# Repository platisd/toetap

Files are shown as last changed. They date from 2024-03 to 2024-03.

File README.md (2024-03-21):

# ToeTap
A human interface device for your toes 🦶⌨️

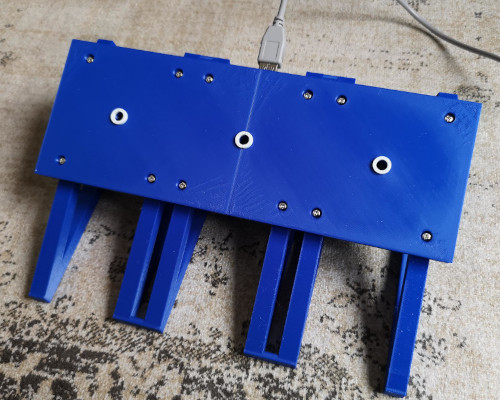
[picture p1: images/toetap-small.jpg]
toetap top view


## What is ToeTap?

ToeTap is a minimalist USB keyboard and mouse that you control by tapping your toes.
It's designed to be used as a foot pedal for gamers, video makers and editors or anyone who wants to keep their hands free while working in front of a computer.
I use it to scroll through my script while recording videos because I hate moving my hand away just to scroll. It shows a bit on the video and it's annoying.
You can easily adjust it to perform any keyboard or mouse action you want. With up to 3 inputs and no moving parts, it's a simple and reliable tool that you can use to improve your workflow.

Compared to commercial foot pedals, ToeTap is probably slightly cheaper if you know how to solder and can program an Arduino. It's also infinitely more customizable since, you know, it's open source. 🍹

## How does it work?

ToeTap is made of some hardware that involve various components, custom made PCBs and a 3D printed case. It's controlled by an Arduino Pro Micro clone, which is a small board that can act as a USB keyboard or mouse. The ATmega32U4 microcontroller by Microchip is connected to 3 photoresistors that are used to detect when you tap/step on them.

### Hardware

The following components are necessary to build ToeTap:
- 3x [ToeTap PCBs](https://www.pcbway.com/project/shareproject/ToeTap_USB_Controller_7fb3b714.html)
- Arduino Pro Micro clone in a "square" form factor where the USB port is part of the board
  - It is often marketed as `Mini SS Micro ATMEGA32U4`
  - You may need to add some electrical tape on the USB side to make sure it doesn't wiggle when you connect it
- 9x 220Ω resistors
- [3D-printed components](https://www.tinkercad.com/things/i6qfPpNWuRz-toetap)

#### PCB Assembly

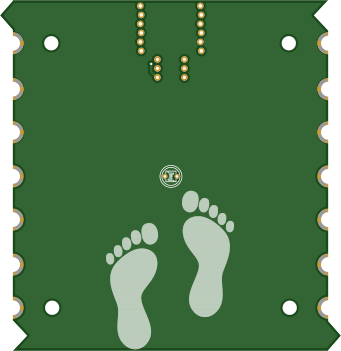
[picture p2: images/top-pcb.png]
top pcb layout
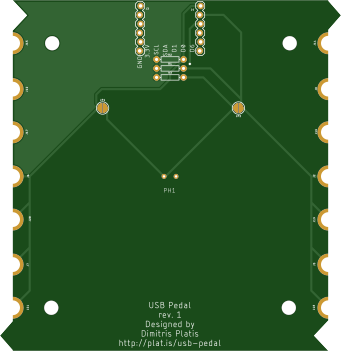
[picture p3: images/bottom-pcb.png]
bottom pcb layout


To build a fully-fledged ToeTap you will need to solder 3 of the ToeTap PCBs together. The PCBs are designed to be soldered together side by side, with the photoresistors on the top side and everything else on the bottom side. The photoresistors are used to detect when you tap on the ToeTap. The bottom side of the PCBs is where the microcontroller and the resistors are soldered.
Additionally, on the bottom side of the two "side" PCBs, you need to solder the "pad" facing towards the middle PCB. By soldering the PCBs together AND the corresponding pads, you will be able to get all the PCBs to work together as a single unit. The pads of the middle PCB should be left unsoldered.
If you need more detailed instructions, open an issue and I'll be happy to help you out.

### Software

The software is written in C++ and is designed to be compiled with the Arduino IDE.
Some basic filtering is applied to the photoresistor readings to detect when you tap on the ToeTap. The readings are then used to trigger a keyboard or mouse action. The software is designed to be easily customizable, so you can change the keybindings and the sensitivity of the ToeTap to suit your needs.

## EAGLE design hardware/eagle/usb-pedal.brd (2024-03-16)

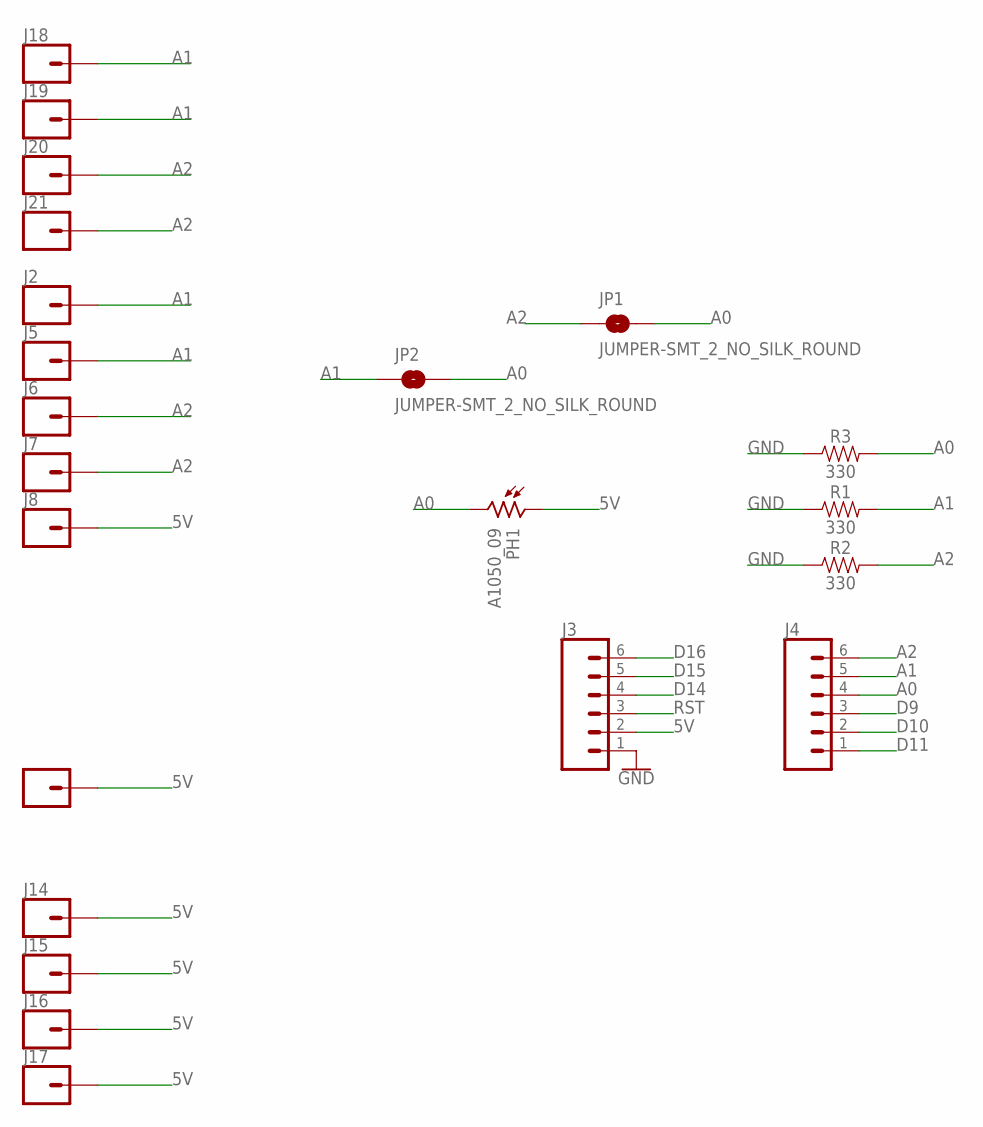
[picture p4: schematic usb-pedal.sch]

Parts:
J2, J5, J6, J7, J8, J12, J14, J15, J16, J17, J18, J19, J20, J21: CONN_01SMTSO-256-ET-0.165DIA; SMTSO-256-ET-0.165DIA
J3, J4: CONN_06LOCK; 1X06_LOCK
JP1, JP2: JUMPER-SMT_2_NO_SILK_ROUND; SMT-JUMPER_2_NO_SILK_ROUND
PH1: A1050_09; T0-46-A10XX
R1, R2, R3: 330; AXIAL-0.3

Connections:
5V: J3.2, J8.P$1, J12.P$1, J14.P$1, J15.P$1, J16.P$1, J17.P$1, PH1.1
A0: J4.4, JP1.2, JP2.2, PH1.2, R3.P$2 (2)
A1: J2.P$1, J4.5, J5.P$1, J18.P$1, J19.P$1, JP2.1, R1.P$2 (2)
A2: J4.6, J6.P$1, J7.P$1, J20.P$1, J21.P$1, JP1.1, R2.P$2 (2)
D9: J4.3
D10: J4.2
D11: J4.1
D14: J3.4
D15: J3.5
D16: J3.6
GND: J3.1, R1.P$1 (1), R2.P$1 (1), R3.P$1 (1)
RST: J3.3

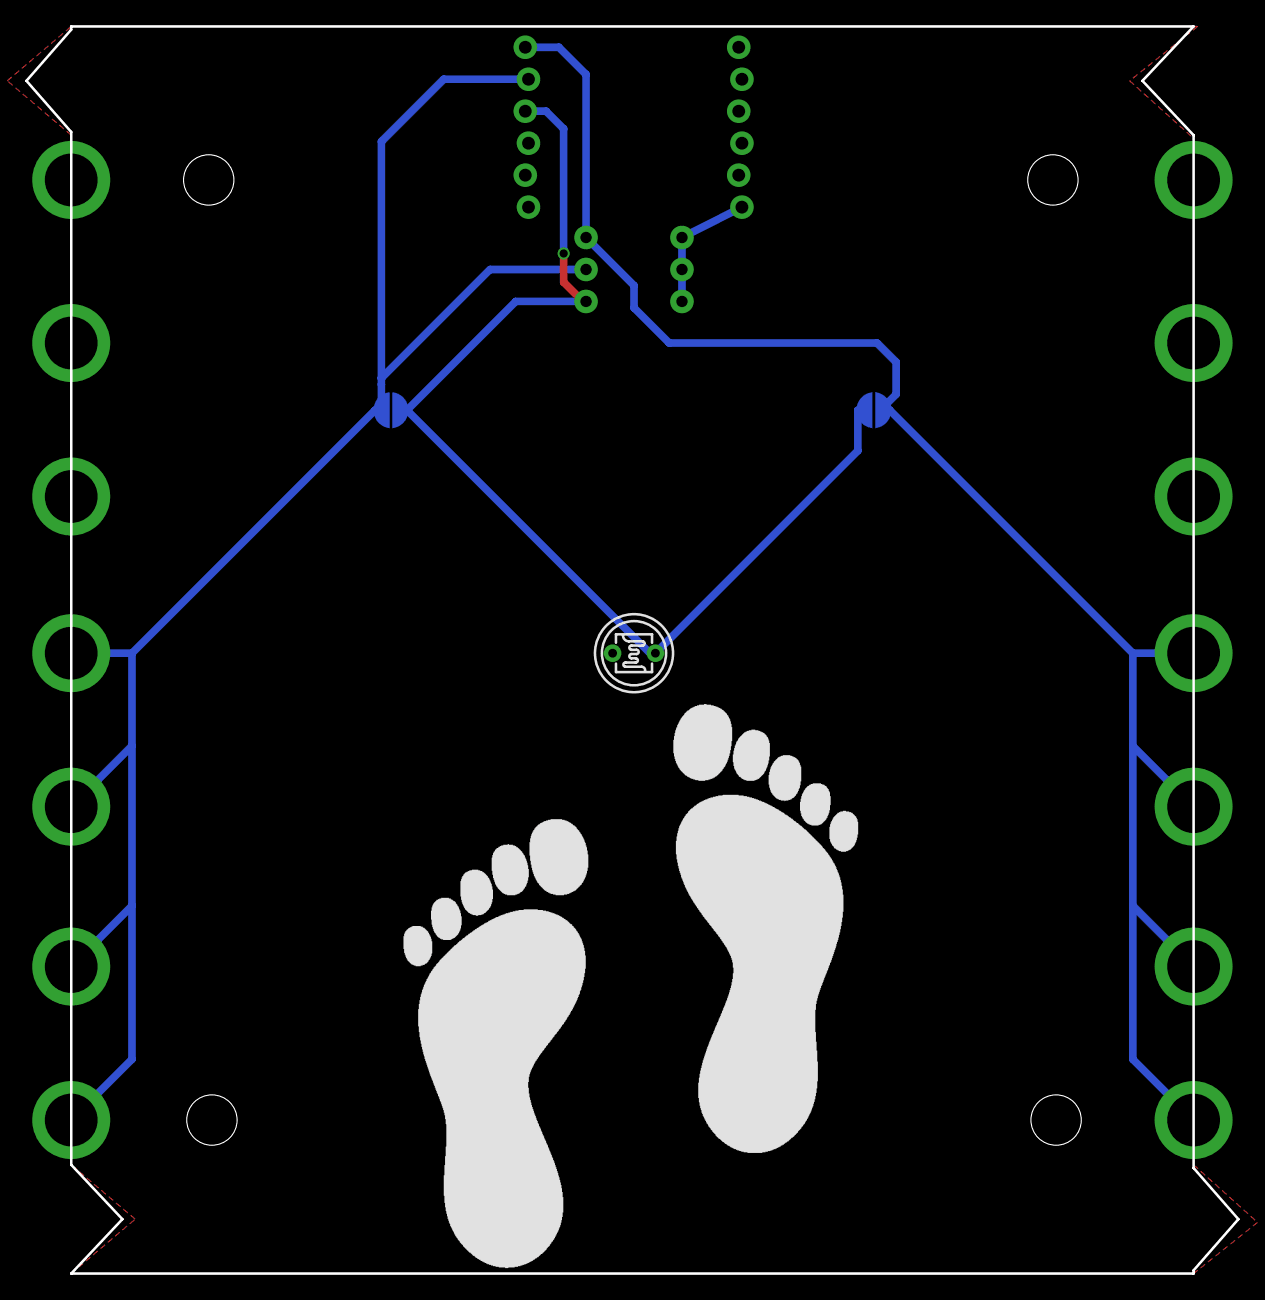
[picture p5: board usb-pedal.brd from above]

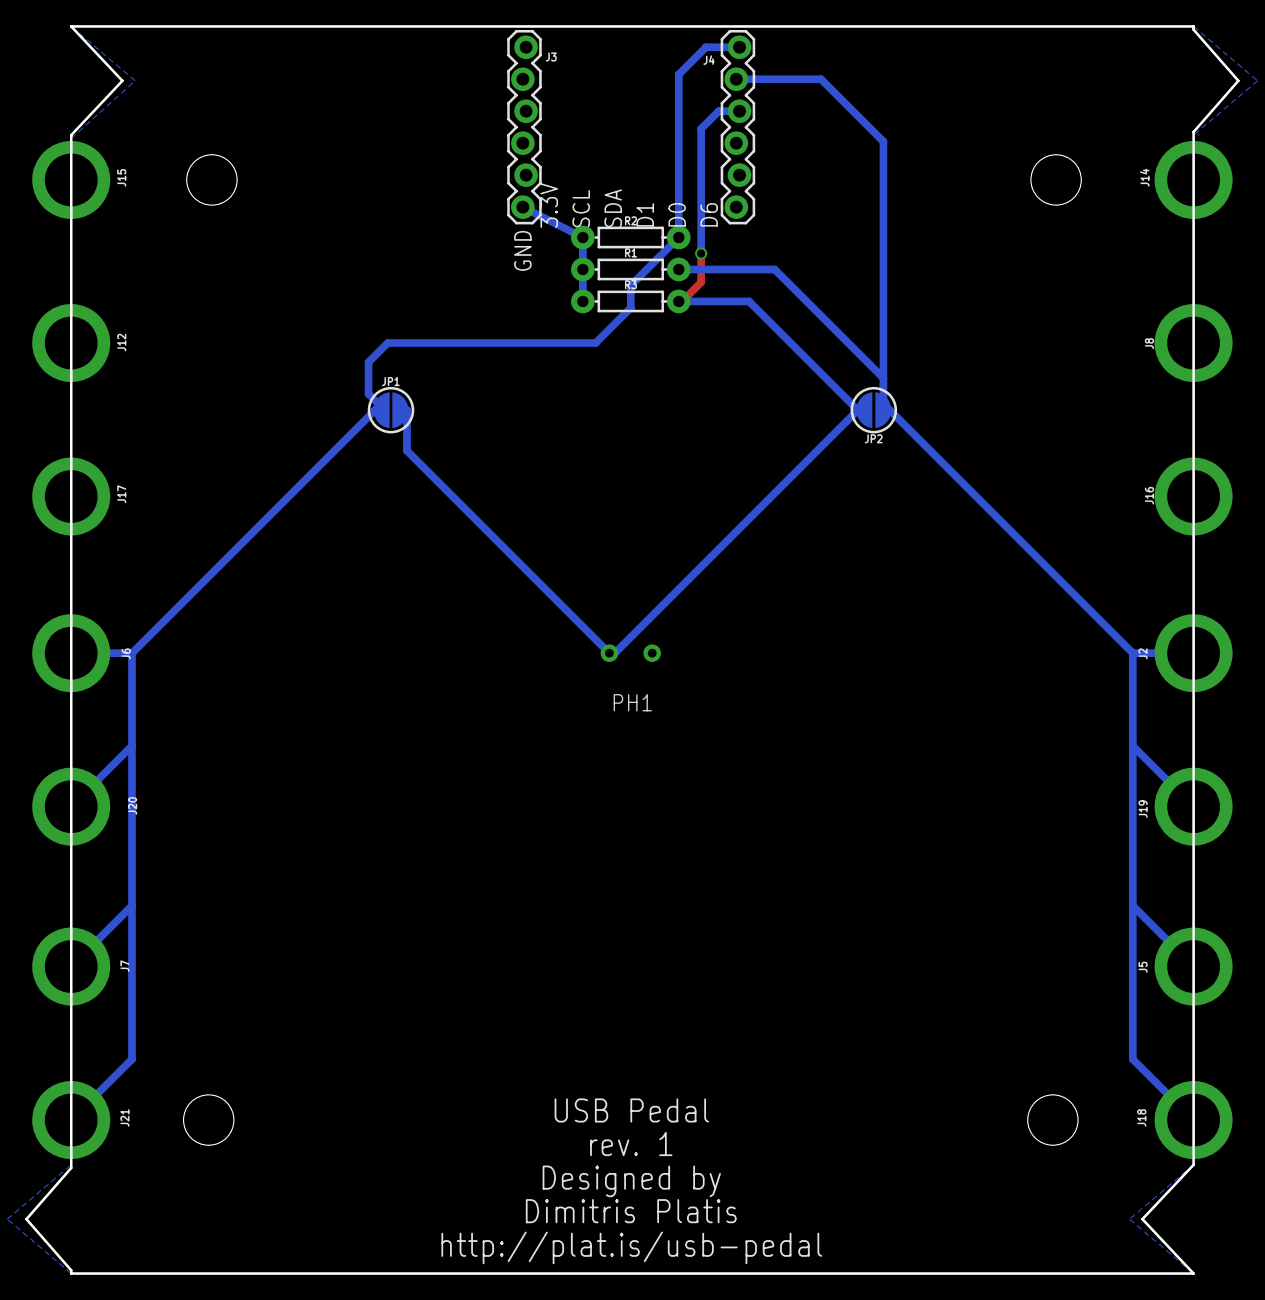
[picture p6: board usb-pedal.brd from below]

Board: 2 copper layers, 96.3 x 99.1 mm, 22 parts (7 on the bottom side), 5 nets.

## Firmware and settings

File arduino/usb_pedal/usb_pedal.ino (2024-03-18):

/**
 * Determine whether the pedal is pressed or not by reading the different
 * photoresistors. Use the Mouse library to send a mouse click when the pedal is
 * pressed. Filter the readings using a moving average to avoid false positives.
 */

#include <Mouse.h>

constexpr int kBufferSize{5};
/// The interval to read the sensor. Affects the responsiveness of the pedal.
/// Lower values will make the pedal more responsive but will also increase the
/// probability of ghost presses (false positives).
constexpr unsigned long kInterval{5UL}; // In milliseconds

class LdrSensor {
public:
  /**
   * @brief Construct a new Ldr Sensor
   *
   * @param pin The analog pin where the sensor is connected
   * @param dark The threshold value under which (inclusive) the sensor is
   * considered pressed
   */
  LdrSensor(uint8_t pin, int dark) : mPin{pin}, mDark{dark} {
    for (auto &value : mBuffer) {
      value = 1023; // Initialize the buffer with the maximum value
    }
  }

  void read() {
    mBuffer[mBufferIndex] = analogRead(mPin);
    mBufferIndex = (mBufferIndex + 1) % kBufferSize;
  }

  bool wasJustPressed() {
    const auto pressed = isPressed();
    const auto wasAlreadyPressed = mPreviouslyPressed;
    mPreviouslyPressed = pressed;
    return pressed && !wasAlreadyPressed;
  }

  /// For debugging purposes
  int getLastReading() const {
    const auto previousIndex = (mBufferIndex - 1 + kBufferSize) % kBufferSize;
    return mBuffer[previousIndex];
  }

private:
  uint8_t mPin{};
  int mDark{};
  int mBuffer[kBufferSize]{0};
  int mBufferIndex{0};
  bool mPreviouslyPressed{false};

  int getAverage() const {
    int sum{0};
    for (auto value : mBuffer) {
      sum += value;
    }
    const float average =
        static_cast<float>(sum) / static_cast<float>(kBufferSize);
    // Round up to the nearest integer to ensure quick reaction
    // to "button up" events
    return static_cast<int>(average + 0.5F);
  }

  bool isPressed() const {
    const auto average = getAverage();
    return average <= mDark;
  }
};

void doLeftSensorAction() {
  Serial.println("Left sensor pressed");
  Mouse.move(0, 0, 1);
}

void doMiddleSensorAction() {
  Serial.println("Middle sensor pressed");
  Mouse.move(0, 0, 5);
}

void doRightSensorAction() {
  Serial.println("Right sensor pressed");
  Mouse.move(0, 0, -1);
}

void setup() {
  Serial.begin(9600);
  Mouse.begin();
}

void loop() {
  static unsigned long lastProcessing{millis()};
  const auto currentTime = millis();

  if (currentTime - lastProcessing < kInterval) {
    return;
  }
  lastProcessing = currentTime;

  // Using a 4-7 kOhm LDR and a 220 Ohm pull-down
  static LdrSensor leftSensor{A1, 1};
  static LdrSensor middleSensor{A0, 1};
  static LdrSensor rightSensor{A2, 1};
  static int measurementsToFillBuffer{0};
  static bool bufferHasBeenFilledOnce{false};

  leftSensor.read();
  middleSensor.read();
  rightSensor.read();

  // Make sure the buffer is filled up once before processing
  if (!bufferHasBeenFilledOnce) {
    if (measurementsToFillBuffer < kBufferSize) {
      ++measurementsToFillBuffer;
      return;
    }
  }
  bufferHasBeenFilledOnce = true;

  if (leftSensor.wasJustPressed()) {
    doLeftSensorAction();
  }
  if (middleSensor.wasJustPressed()) {
    doMiddleSensorAction();
  }
  if (rightSensor.wasJustPressed()) {
    doRightSensorAction();
  }
}

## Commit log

2024-03-16 Add rev.0 hardware schematics
    Errata: The microcontroller board needs to be placed
    'upside-down', i.e. not as implied by the silkscreen
    on the bottom layer of the board.
    If in doubt, get in touch and we can verify the placement
    together.
    The next revision will address this issue. Comitting this
    for historical reasons as it was the one actually manufactured
    by me.
    [usb-pedal.brd, usb-pedal.sch]
2024-03-16 Add rev.1 board
    Rev.1 solves the slight inconsistency of rev.0's microcontroller
    board placement.
    Now the board should be placed 'as you see it' while in the previous
    version the silkscreen didn't actually match the correct board placement.
    [usb-pedal.brd]
2024-03-16 Add arduino sketch
    The sketch detects (after some basic filtering) when it receives no light,
    or in other words is being stepped on, and scrolls the mouse.
    The sketch can be adjusted for any other action supported by the Keyboard and Mouse libraries.
2024-03-18 Scroll down with the right leg/sensor
2024-03-21 Fix the number of resistors
    We need 3 resistors per board, so 9 in total

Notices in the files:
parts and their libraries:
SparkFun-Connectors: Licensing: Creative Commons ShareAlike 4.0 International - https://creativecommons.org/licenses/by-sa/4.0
